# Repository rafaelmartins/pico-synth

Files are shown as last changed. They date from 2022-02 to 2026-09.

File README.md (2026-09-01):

<!-- github-to-forgejo:notice:start -->
> [!IMPORTANT]
> Development has moved to [https://git.rafaelmartins.com/rafaelmartins/pico-synth](https://git.rafaelmartins.com/rafaelmartins/pico-synth). Please check [https://git.rafaelmartins.com/](https://git.rafaelmartins.com/) for details on how to contribute.
<!-- github-to-forgejo:notice:end -->

# pico-synth

A Raspberry Pi Pico based digital synthesizer.

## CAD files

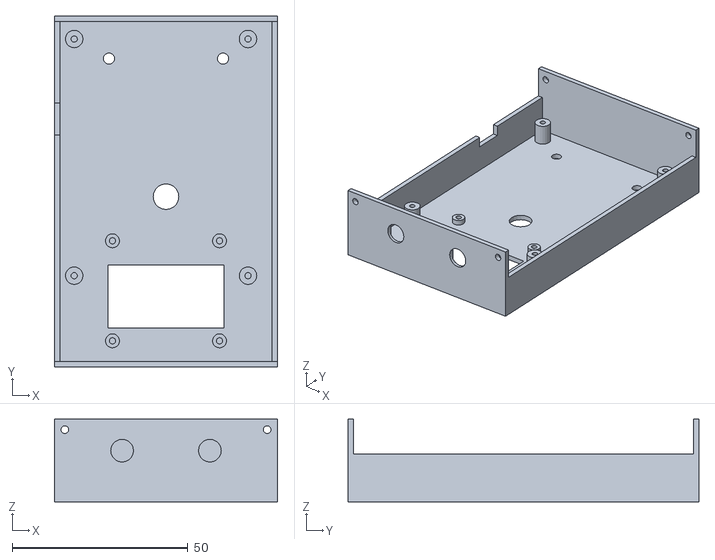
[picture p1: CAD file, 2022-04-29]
3d-models/enclosure.stl
63.6 x 100.0 x 23.6

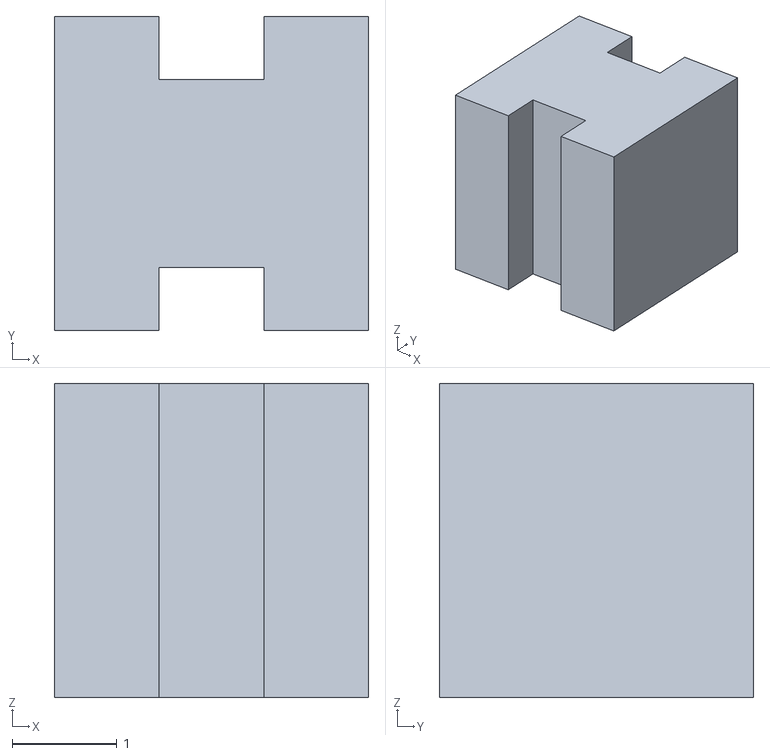
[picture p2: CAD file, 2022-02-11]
3d-models/led-holder.stl
3.00 x 3.00 x 3.00

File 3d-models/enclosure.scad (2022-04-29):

/*
 * SPDX-FileCopyrightText: 2021-2022 Rafael G. Martins <rafael@rafaelmartins.eng.br>
 * SPDX-License-Identifier: CERN-OHL-S-2.0
 */

thickness = 1.6;

width = 100;
length = 1 + (29.71 + thickness) * 2;

pcb_width = 74.549;
pcb_length = 56.642;
pcb_thickness = 1.6;
pcb_screw_padding = 3.56;
pcb_base_height = 6.5;
pcb_base_d = 5;
pcb_base_screw_d = 1.8;

pcb0_x = thickness + 0.5;
pcb0_y = width - pcb_width - 3;

usb_conn_width = 9.1;
usb_conn_height = 3.9;
usb_conn_distance_y = 43.595;

height = thickness + pcb_base_height + pcb_thickness + usb_conn_height + 10;

oled_hole_z = 3;
oled_hole_base_z = 1.65;
oled_hole_base_d = 4;
oled_hole_d = 1.8;
oled_hole_spacing_x = 30.5;
oled_hole_spacing_y = 28.5;
oled0_x = (length - oled_hole_spacing_x) / 2;
oled0_y = pcb0_y - 15;
oled_screen_width = 33;
oled_screen_height = 18;
oled_screen_distance_x = (oled_hole_spacing_x - oled_screen_width) / 2;
oled_screen_distance_y = 3.6;

encoder_distance_x = 29.711;
encoder_distance_y = 26.075;
encoder_d = 7.3;

led_d = 3.2;
led_distance_x = 13.467;
led_distance_y = 65.405;
led_spacing = 32.502;

jack_d = 5.8 + 0.7;
jack_out_d = 8.5;
jack_spacing = 25;
jack_distance_x = (length - jack_spacing) / 2;
jack_distance_z = height - 9;

module pcb_base(x, y) {
    translate([x, y, 0]) {
        difference() {
            cylinder(pcb_base_height, d=pcb_base_d, $fn=20);
            cylinder(pcb_base_height, d=pcb_base_screw_d, $fn=20);
        }
    }
}

difference() {
    union() {
        cube([length, width, thickness]);
        translate([0, 0, thickness]) {
            cube([thickness, width, pcb_base_height + pcb_thickness + usb_conn_height]);
            cube([length, thickness, height - thickness]);
            translate([length - thickness, 0, 0])
                cube([thickness, width, pcb_base_height + pcb_thickness + usb_conn_height]);
            translate([0, width - thickness, 0])
                cube([length, thickness, height - thickness]);
        }

        translate([pcb0_x, pcb0_y, thickness]) {
            pcb_base(pcb_screw_padding, pcb_screw_padding);
            pcb_base(pcb_screw_padding, pcb_width - pcb_screw_padding);
            pcb_base(pcb_length - pcb_screw_padding, pcb_screw_padding);
            pcb_base(pcb_length - pcb_screw_padding, pcb_width - pcb_screw_padding);
        }

        translate([oled0_x, oled0_y, thickness]) {
            cylinder(h=oled_hole_base_z, d=oled_hole_base_d, $fn=20);
            translate([oled_hole_spacing_x, 0, 0])
                cylinder(h=oled_hole_base_z, d=oled_hole_base_d, $fn=20);
            translate([0, oled_hole_spacing_y, 0]) {
                cylinder(h=oled_hole_base_z, d=oled_hole_base_d, $fn=20);
                translate([oled_hole_spacing_x, 0, 0])
                    cylinder(h=oled_hole_base_z, d=oled_hole_base_d, $fn=20);
            }
        }

    }

    translate([0, pcb0_y, thickness]) {
        translate([0, usb_conn_distance_y, pcb_base_height + pcb_thickness + 0.5])
            cube([thickness, usb_conn_width, usb_conn_height - 0.5 + 0.1]);
    }

    translate([pcb0_x, pcb0_y, 0]) {
        translate([encoder_distance_x, encoder_distance_y, 0])
            cylinder(thickness, d=encoder_d, $fn=20);
        translate([led_distance_x, led_distance_y, 0]) {
            cylinder(thickness, d=led_d, $fn=20);
            translate([led_spacing, 0, 0])
                cylinder(thickness, d=led_d, $fn=20);
        }
    }

    translate([oled0_x, oled0_y, 0]) {
        translate([oled_screen_distance_x, oled_screen_distance_y, 0])
            cube([oled_screen_width, oled_screen_height, thickness]);

        translate([0, 0, thickness + oled_hole_base_z - oled_hole_z + 0.1]) {
            cylinder(h=oled_hole_z, d=oled_hole_d, $fn=20);
            translate([oled_hole_spacing_x, 0, 0])
                cylinder(h=oled_hole_z, d=oled_hole_d, $fn=20);
            translate([0, oled_hole_spacing_y, 0]) {
                cylinder(h=oled_hole_z, d=oled_hole_d, $fn=20);
                translate([oled_hole_spacing_x, 0, 0])
                    cylinder(h=oled_hole_z, d=oled_hole_d, $fn=20);
            }
        }
    }

    rotate([-90, 0, 0]) {
        translate([jack_distance_x, -jack_distance_z, 0]) {
            translate([0, 0, thickness - 0.6])
                cylinder(0.6, d=jack_out_d, $fn=20);
            cylinder(thickness, d=jack_d, $fn=20);

            translate([jack_spacing, 0, 0]) {
                translate([0, 0, thickness - 0.6])
                    cylinder(0.6, d=jack_out_d, $fn=20);
                cylinder(thickness, d=jack_d, $fn=20);
            }
        }

        translate([3, -height + 3, 0])
            cylinder(width, d=2.2, $fn=20);
        translate([length - 3, -height + 3, 0])
            cylinder(width, d=2.2, $fn=20);
    }
}

rotate([-90, 0, 0]) {
    translate([jack_distance_x, -jack_distance_z, 0]) {
        translate([0.5 + jack_d / 2, 0, thickness / 2])
            cube([1, jack_d, thickness], center=true);
        translate([-0.5 - jack_d / 2, 0, thickness / 2])
            cube([1, jack_d, thickness], center=true);

        translate([jack_spacing, 0, 0]) {
            translate([0.5 + jack_d / 2, 0, thickness / 2])
                cube([1, jack_d, thickness], center=true);
            translate([-0.5 - jack_d / 2, 0, thickness / 2])
                cube([1, jack_d, thickness], center=true);
        }
    }
}

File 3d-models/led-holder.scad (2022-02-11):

/*
 * SPDX-FileCopyrightText: 2021-2022 Rafael G. Martins <rafael@rafaelmartins.eng.br>
 * SPDX-License-Identifier: CERN-OHL-S-2.0
 */

// print two of this

margin = 1;
width = 3;
height = 3;
led_width = 1.8;
led_length = 1;
length = 2 * margin + led_length;

difference() {
    cube([length, width, height]);
    translate([margin, 0, 0]) {
        cube([led_length, (width - led_width) / 2, height]);
        translate([0, width - ((width - led_width) / 2), 0])
            cube([led_length, (width - led_width) / 2, height]);
    }
}

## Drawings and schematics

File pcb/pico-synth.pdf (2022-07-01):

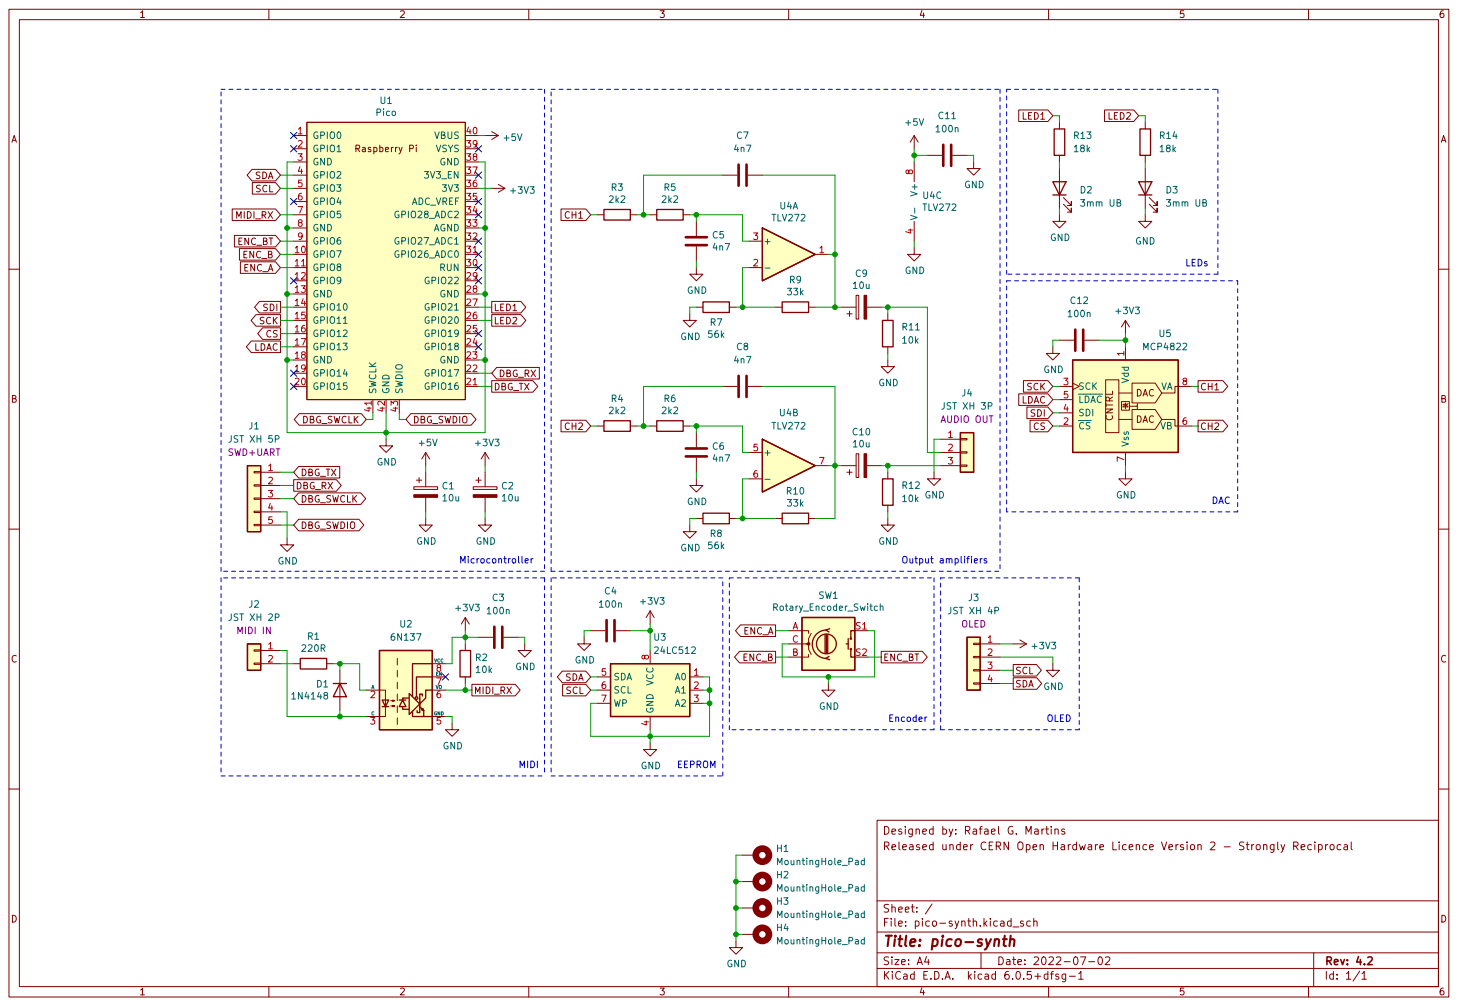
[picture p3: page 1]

1 ~{CS} 2 SCK 3 SDI 4 ~{LDAC} 5 VB 6 Vss 7 VA 8 U5 MCP4822 GND GND

JST XH 2P MIDI IN

4 SDA 5 SCL 6 WP 7 VCC

Designed by: Rafael G. Martins
File: pico-synth.kicad_sch Sheet: / Released under CERN Open Hardware Licence Version 2 - Strongly Reciprocal

Id: 1/1 Title: pico-synth

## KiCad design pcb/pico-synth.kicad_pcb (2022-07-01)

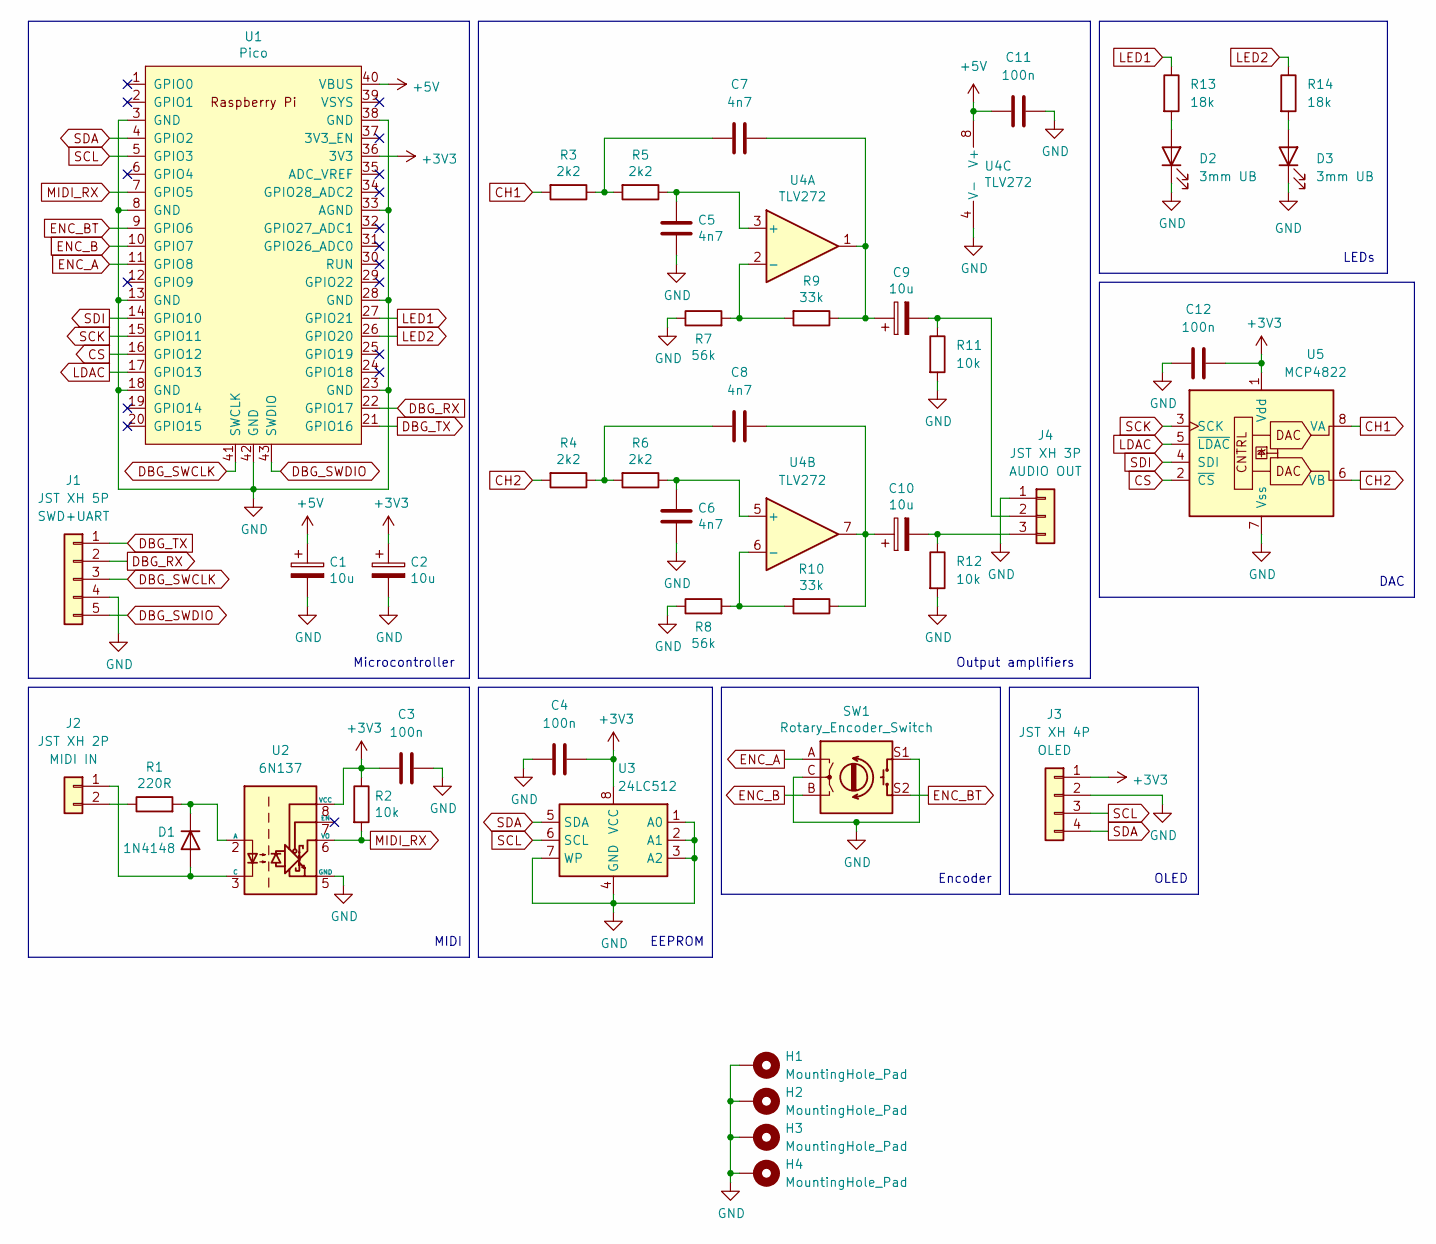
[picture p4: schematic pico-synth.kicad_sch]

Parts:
C1, C2, C9, C10: 10u; CP_Radial_D5.0mm_P2.50mm
C3, C4, C11, C12: 100n; C_Disc_D4.3mm_W1.9mm_P5.00mm
C5, C6, C7, C8: 4n7; C_Rect_L7.0mm_W2.5mm_P5.00mm
D1: 1N4148; D_DO-35_SOD27_P7.62mm_Horizontal
D2, D3: 3mm UB; LED_D3.0mm
H1, H2, H3, H4: MountingHole_Pad; MountingHole_2.2mm_M2_Pad_Via
J1: JST XH 5P; JST_XH_B5B-XH-A_PinSocket_1x05_P2.50mm_Vertical
J2: JST XH 2P; JST_XH_B2B-XH-A_PinSocket_1x02_P2.50mm_Vertical
J3: JST XH 4P; JST_XH_B4B-XH-A_PinSocket_1x04_P2.50mm_Vertical
J4: JST XH 3P; JST_XH_B3B-XH-A_PinSocket_1x03_P2.50mm_Vertical
R1: 220R; R_Axial_DIN0207_L6.3mm_D2.5mm_P10.16mm_Horizontal
R2, R11, R12: 10k; R_Axial_DIN0207_L6.3mm_D2.5mm_P10.16mm_Horizontal
R3, R4, R5, R6: 2k2; R_Axial_DIN0207_L6.3mm_D2.5mm_P10.16mm_Horizontal
R7, R8: 56k; R_Axial_DIN0207_L6.3mm_D2.5mm_P10.16mm_Horizontal
R9, R10: 33k; R_Axial_DIN0207_L6.3mm_D2.5mm_P10.16mm_Horizontal
R13, R14: 18k; R_Axial_DIN0207_L6.3mm_D2.5mm_P10.16mm_Horizontal
SW1: Rotary_Encoder_Switch; RotaryEncoder_Alps_EC11E-Switch_Vertical_H20mm_CircularMoun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
U1: Pico; RPi_Pico_SMD_TH
U2: 6N137; DIP-8_W7.62mm
U3: 24LC512; DIP-8_W7.62mm
U4: TLV272; DIP-8_W7.62mm
U5: MCP4822; DIP-8_W7.62mm

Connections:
+3V3: C2.1, C3.1, C4.2, C12.2, J3.1, R2.1, U1.36 (3V3), U2.8 (VCC), U3.8 (VCC), U5.1 (Vdd)
+5V: C1.1, C11.1, U1.40 (VBUS), U4.8 (V+)
CH1: R3.2, U5.8 (VA)
CH2: R4.2, U5.6 (VB)
CS: U1.16 (GPIO12), U5.2 (~CS)
DBG_RX: J1.2, U1.22 (GPIO17)
DBG_SWCLK: J1.3, U1.41 (SWCLK)
DBG_SWDIO: J1.5, U1.43 (SWDIO)
DBG_TX: J1.1, U1.21 (GPIO16)
ENC_A: SW1.A, U1.11 (GPIO8)
ENC_B: SW1.B, U1.10 (GPIO7)
ENC_BT: SW1.S2, U1.9 (GPIO6)
GND: C1.2, C2.2, C3.2, C4.1, C5.2, C6.2, C11.2, C12.1, D2.1 (K), D3.1 (K), H1.1, H2.1, H3.1, H4.1, J1.4, J3.2, J4.1, R7.1, R8.1, R11.2, R12.2, SW1.C, SW1.S1, U1.3 (GND), U1.8 (GND), U1.13 (GND), U1.18 (GND), U1.23 (GND), U1.28 (GND), U1.33 (AGND), U1.38 (GND), U1.42 (GND), U2.5 (GND), U3.1 (A0), U3.2 (A1), U3.3 (A2), U3.4 (GND), U3.7 (WP), U4.4 (V-), U5.7 (Vss)
LDAC: U1.17 (GPIO13), U5.5 (~LDAC)
LED1: R13.1, U1.27 (GPIO21)
LED2: R14.1, U1.26 (GPIO20)
MIDI_RX: R2.2, U1.7 (GPIO5), U2.6 (VO)
unnamed: C5.1, R5.1, U4.3 (+)
unnamed: C6.1, R6.1, U4.5 (+)
unnamed: C7.1, R3.1, R5.2
unnamed: C7.2, C9.1, R9.1, U4.1
unnamed: C8.1, R4.1, R6.2
unnamed: C9.2, J4.2, R11.1
unnamed: C8.2, C10.1, R10.1, U4.7
unnamed: C10.2, J4.3, R12.1
unnamed: D1.1 (K), R1.2, U2.2 (A)
unnamed: D1.2 (A), J2.1, U2.3 (C)
unnamed: D2.2 (A), R13.2
unnamed: D3.2 (A), R14.2
unnamed: J2.2, R1.1
unnamed: R7.2, R9.2, U4.2 (-)
unnamed: R8.2, R10.2, U4.6 (-)
SCK: U1.15 (GPIO11), U5.3 (SCK)
SCL: J3.3, U1.5 (GPIO3), U3.6 (SCL)
SDA: J3.4, U1.4 (GPIO2), U3.5 (SDA)
SDI: U1.14 (GPIO10), U5.4 (SDI)

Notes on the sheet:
EEPROM
Output amplifiers
LEDs
OLED
Encoder
Microcontroller
MIDI
DAC

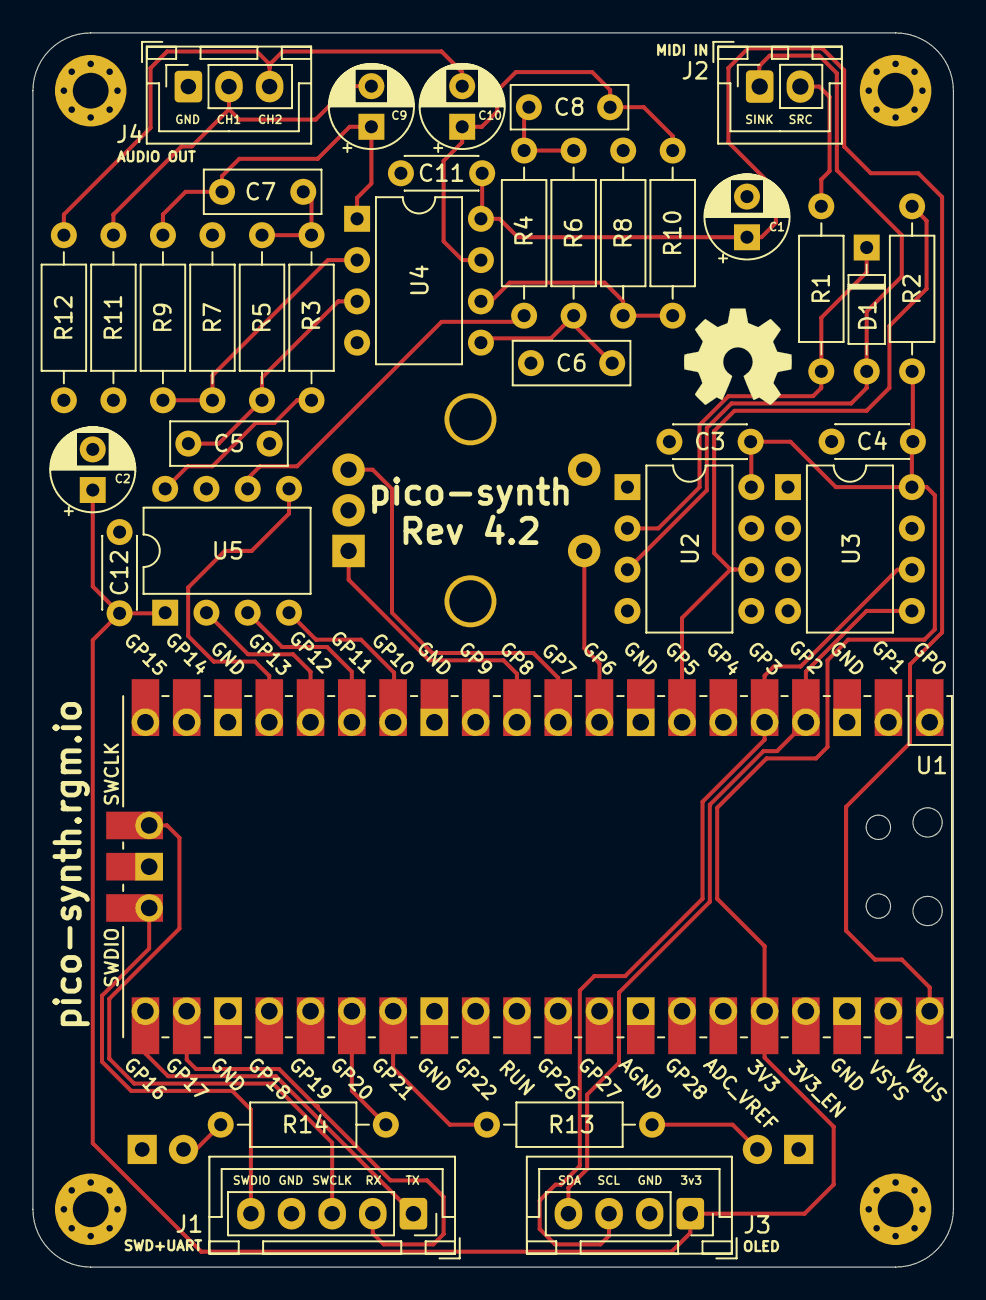
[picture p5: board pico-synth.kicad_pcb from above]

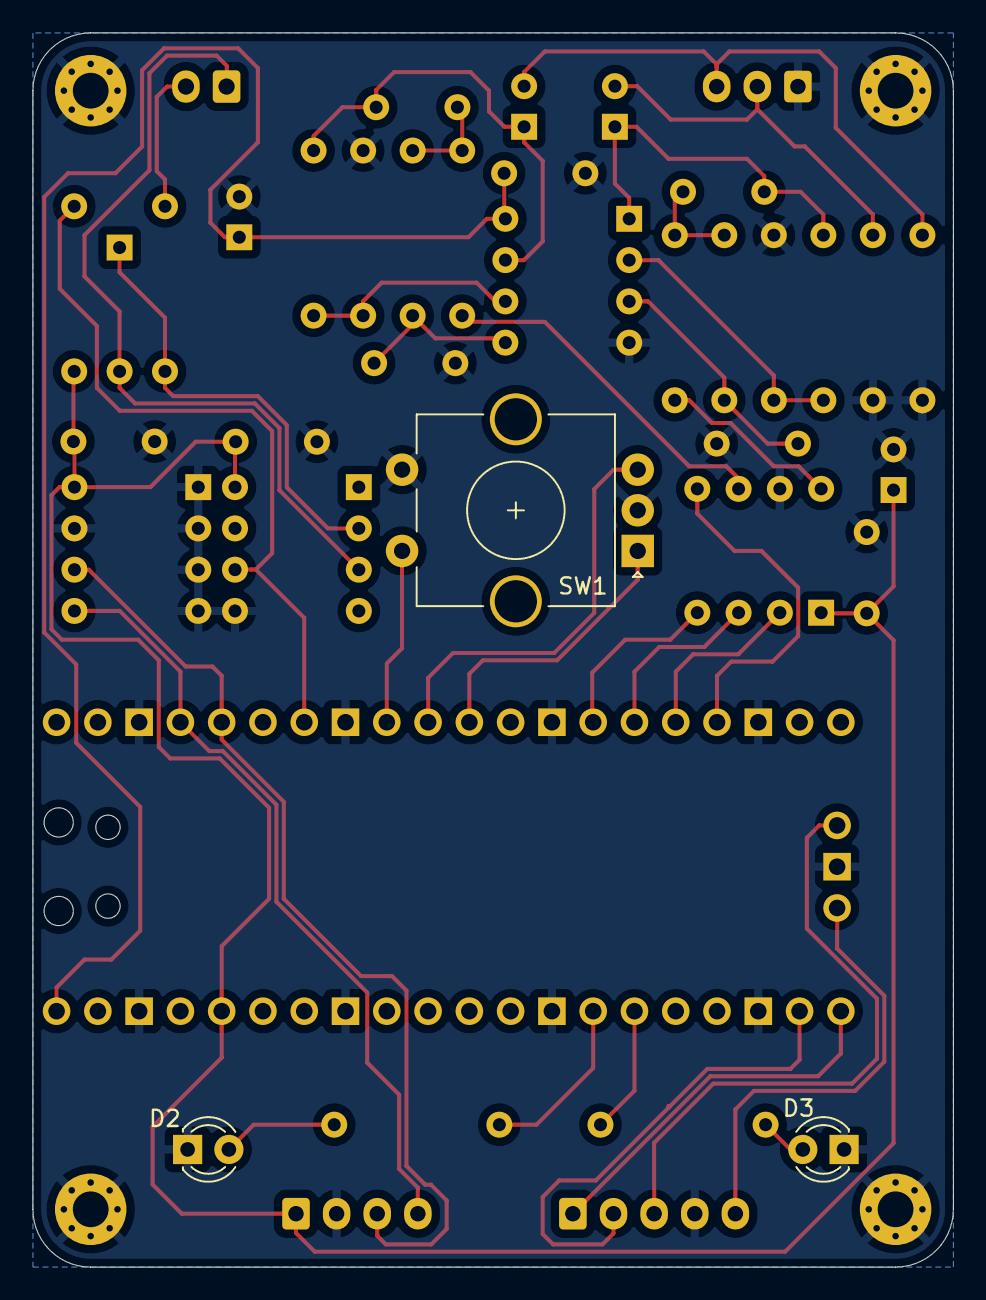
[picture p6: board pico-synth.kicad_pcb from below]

Board: 2 copper layers, 56.6 x 75.9 mm, 43 parts (3 on the bottom side), 36 nets.

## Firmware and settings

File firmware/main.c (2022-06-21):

/*
 * pico-synth: A Raspberry Pi Pico based digital synthesizer.
 *
 * SPDX-FileCopyrightText: 2021-2022 Rafael G. Martins <rafael@rafaelmartins.eng.br>
 * SPDX-License-Identifier: BSD-3-Clause
 */

#include <pico/multicore.h>
#include "synth.h"

static synth_t synth = {
    .stdio = {
        .uart = uart0,
        .uart_baud_rate = 115200,
        .uart_tx = 16,
        .uart_rx = 17,
    },

    .engine.dac = {
        .pio = pio0,
        .state_machine = 0,
        .basepin = 10,
        .with_ldac = true,
    },

    .midi = {
        .uart = {
            .uart = uart1,
            .uart_rx = 5,
        },

        .usb = {
            .enable = true,
            .vid = 0x1d50,  // OpenMoko, Inc.
            .pid = 0x6179,  // pico-synth
            .version = 0x0100,
            .product = "pico-synth",
        },

        .ctx_data = &synth,
    },

    .tui = {
        .i2c = {
            .i2c = i2c1,
            .baudrate = 400000,
            .basepin = 2,
        },

        .eeprom = {
            .ic = PS_TUI_EEPROM_24LC512,
            .base_address = &synth.settings,
            .max_offset = sizeof(synth.settings),
        },

        .encoder = {
            .button = 6,
            .a = 8,
            .b = 7,
            .button_debounce_us = 250000,
            .rotate_debounce_us = 2000,
        },

        .oled = {
            .controller = PS_TUI_OLED_SH1106,
        },

        .ctx_data = &synth,
    },

    .channels = {
        {
            .with_led = true,
            .led = 21,
        },
        {
            .with_led = true,
            .led = 20,
        },
    },
};


static void
main1(void)
{
    synth_core1(&synth);
}


int
main(void)
{
    synth_init(&synth);
    multicore_launch_core1(main1);
    synth_core0(&synth);
    return 0;
}

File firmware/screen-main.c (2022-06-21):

/*
 * pico-synth: A Raspberry Pi Pico based digital synthesizer.
 *
 * SPDX-FileCopyrightText: 2021-2022 Rafael G. Martins <rafael@rafaelmartins.eng.br>
 * SPDX-License-Identifier: BSD-3-Clause
 */

#include <stdio.h>
#include "synth.h"
#include "screen-settings.h"
#include "screen-main.h"


static void
render(ps_tui_t *tui)
{
    synth_t *s = tui->ctx_data;
    char buf[20];

    ps_tui_oled_clear(tui);
    ps_tui_oled_line(tui, 0, "pico-synth", PS_TUI_OLED_HALIGN_CENTER);

    for (uint8_t i = 0; i < EEPROM_VOICE_COUNT; i++) {
        eeprom_preset_t *p = &s->settings.presets[s->settings.voices[i].preset];
        snprintf(buf, sizeof(buf), "%d: %s (%d)", i + 1,
                 p->name[0] == 0 ? "NO NAME" : p->name,
                 s->settings.voices[i].preset);
        ps_tui_oled_line(tui, (i + 1) * 3, buf, PS_TUI_OLED_HALIGN_LEFT);

        snprintf(buf, sizeof(buf), "   MIDI Channel: %d",
                 s->settings.voices[i].midi_channel);
        ps_tui_oled_line(tui, (i + 1) * 3 + 1, buf, PS_TUI_OLED_HALIGN_LEFT);
    }
}


static void
encoder(ps_tui_t *tui, ps_tui_encoder_action_t act)
{
    if (act != PS_TUI_ENCODER_ACTION_BUTTON)
        return;

    ps_tui_screen_load(tui, &screen_settings);
}


static const ps_tui_screen_func_t func = {
    .render_func = render,
    .encoder_func = encoder,
};

const ps_tui_screen_t screen_main = {
    .type = PS_TUI_SCREEN_FUNC,
    .func = &func,
};

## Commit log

2021-06-07 *: oscillator simplification (incomplete). allow using single dac
    [main.c]
2021-06-07 mcp4822: oscillator: waveform: use int16_t for samples
    this makes it easier for our future envelopes/filters/effects to work
    with the samples.
2021-06-07 mcp4822: clip samples if exceeded hardware range
2021-06-08 controller: midi changes for tinyusb-0.10.1/pico-sdk-1.2.0
2021-06-18 main: updates for new prototype, bare minimum that compiles
2021-06-18 added ec11-like encoder library. not used yet
2021-06-19 midi: reset data after callback call
    [midi.c]
2021-07-04 added eeprom-i2c (24LC256) library. not used yet
2021-08-08 eeprom-i2c: support 24LC512
2021-08-14 synth: offload sample evaluation from core1
2022-01-29 added kicad project for hardware revision 2.0
    this was already fabricated. gerber included.
    [pico-synth.kicad_pcb, pico-synth.sch]
2022-01-29 added main enclosure 3d model
    [enclosure.scad, enclosure.stl]
2022-02-01 new hardware revision: 2.1
    this adds a two leds, for output monitoring
    [pico-synth.kicad_pcb, pico-synth.sch]
2022-02-11 3d-models: update enclosure
    [enclosure.scad, enclosure.stl]
2022-02-11 3d-models: added led holder
    [led-holder.scad, led-holder.stl]
2022-04-09 pcb: upgrade to kicad 6
    [pico-synth.kicad_pcb, pico-synth.kicad_sch, pico-synth.sch]
2022-04-11 new hardware revision: 3.0
    - added better output filter (Sallen-Key low pass filter)
    - use MCP4822's LDAC pin to avoid (minimal, negligible :) phase drift
    between the channels
    [pico-synth.kicad_pcb, pico-synth.kicad_sch]
2022-04-11 firmware: tui: basic drivers
2022-04-11 firmware: engine: added mcp4822 driver
2022-04-11 firmware: engine: mcp4822: support ldac pin
2022-04-15 firmware: engine: split modules into source and filters
2022-04-15 firmware: engine: oscillator: remove unset note, add sync
    note duration should be handled afterwards by a gate or envelope.
    also includes other minor improvements.
    [main.c]
2022-04-23 firmware: engine: interpolate samples
2022-04-26 firmware: engine: amplifier: hold mutex in sample func
2022-04-29 pcb: new hardware revision: 4.0
    [pico-synth.kicad_pcb, pico-synth.kicad_sch]
2022-04-29 3d-models: update enclosure model for PCB revision 4.0
    [enclosure.scad, enclosure.stl]
2022-05-06 pcb: remove old schematic cache library
2022-05-06 pcb: remove local kicad project settings
2022-05-09 firmware: implement some basic midi polyphony
    maybe my ears are tired, but it sounds slightly detuned
2022-05-09 firmware: engine: support running without sink
    in this case only one voice per channel is supported, and the end of the
    filter chain is plugged directly to output
2022-05-11 firmware: use leds for channel gates
2022-05-16 firmware: fix stdio struct naming
    [main.c, synth.c]
2022-05-19 firmware: split core0 init, to fix uart for core1
    [main.c, synth.c]
2022-05-23 main: avoid compiler warning
    [main.c]
2022-06-06 build: generate bom html
2022-06-11 firmware: tui: add function to reload current screen
2022-06-12 firmware: tui: eeprom driver improvements
2022-06-13 firmware: midi: avoid global variables
    [main.c, midi.c, synth.c]
2022-06-19 firmware: midi: enable uart fifo, otherwise delayed event is lost
2022-06-21 firmware: added basic eeprom preset support and ui screens
    most of the ui is implemented, missing:
    - preset name editing (must implement a screen type to edit strings).
    - eeprom save and eeprom clean actions (maybe implement a confirmation
    screen type).
    [main.c, screen-main.c]
2022-07-01 pcb: new hardware revision: 4.2
    [pico-synth.kicad_pcb, pico-synth.kicad_sch]
